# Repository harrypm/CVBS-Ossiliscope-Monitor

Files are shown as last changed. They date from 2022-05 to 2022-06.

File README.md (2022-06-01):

# CVBS-Oscilloscope-Monitor

This repository is a KiCAD transcription of a circuit by Alan Wolfe.

## Description

The following circuit converts a composite signal and splits the signal as such that it can display video on analog-style oscilloscopes using X,Y & Z inputs.

## Features

- LED indicator - Used for monitoring power
- Power jacks/pads - choice between barrel jack or 3.96mm headers
- BNC connectors for inputs and outputs

- 2 flexable versions depending on users needs

## [THT](CVBS-Ossiliscope-Monitor/Releases/THT) Through Hole (Hand Soldering Version)

This version is simmaller to the equipmnet its intended to be used with as every single part is hand user replaceable simply fabricate the bare boards and order the parts acording the to BOM list.

## [SMD](CVBS-Ossiliscope-Monitor/Releases/SMD) Surface Mount (Factory Frabrication Version)

This version following modern fabrication standards is intended for ease of automated fabraication allowing drag and drop 1-2-3 ordering from services like PCBway or JLCPCB.

## Additional information

Links :

* [PDF link](https://www.qsl.net/w2aew/W2AEW_NTSC_to_scope.pdf)
* [Youtube](https://www.youtube.com/watch?v=yf4kOMSPbM0&start=55)

## Credits

Transcription - Charles Garcia [@cgarcia2097](https://github.com/cgarcia2097)

Orignal Circuit - Alan Wolfe [PDF link](https://www.qsl.net/w2aew/W2AEW_NTSC_to_scope.pdf)

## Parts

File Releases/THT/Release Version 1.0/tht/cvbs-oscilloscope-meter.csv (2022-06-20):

Source: | /home/animeman/Documents/GitHub/CVBS-Ossiliscope-Monitor/tht/cvbs-oscilloscope-meter.kicad_sch
Date: | Mon 06 Jun 2022 10:54:27 PM EDT
Tool: | Eeschema 6.0.5
Generator: | /app/share/kicad/plugins/bom_csv_grouped_by_value.py
Component Count: | 54
Individual Components:
Item | Qty | Reference(s) | Value | LibPart | Footprint | Datasheet
 |  | C1 | 100n | Device:C | Capacitor_THT:C_Disc_D7.5mm_W2.5mm_P5.00mm | ~
 |  | C2 | 22n | Device:C | Capacitor_THT:C_Disc_D7.5mm_W2.5mm_P5.00mm | ~
 |  | C3 | 0.1u | Device:C | Capacitor_THT:C_Disc_D7.5mm_W2.5mm_P5.00mm | ~
 |  | C4 | 0.1u | Device:C | Capacitor_THT:C_Disc_D7.5mm_W2.5mm_P5.00mm | ~
 |  | C5 | 10n | Device:C | Capacitor_THT:C_Disc_D7.5mm_W2.5mm_P5.00mm | ~
 |  | C6 | 10u | Device:C_Polarized_Small_US | Capacitor_THT:CP_Radial_D8.0mm_P3.50mm | ~
 |  | C7 | 0.1u | Device:C_Small | Capacitor_THT:C_Disc_D7.5mm_W2.5mm_P5.00mm | ~
 |  | C8 | 10u | Device:C_Polarized_Small_US | Capacitor_THT:CP_Radial_D8.0mm_P3.50mm | ~
 |  | C9 | 0.33u | Device:C_Small | Capacitor_THT:C_Disc_D7.5mm_W2.5mm_P5.00mm | ~
 |  | C10 | 0.1u | Device:C_Small | Capacitor_THT:C_Disc_D7.5mm_W2.5mm_P5.00mm | ~
 |  | C11 | 10u | Device:C_Polarized_Small_US | Capacitor_THT:CP_Radial_D8.0mm_P3.50mm | ~
 |  | C16 | 10u | Device:C_Polarized_Small_US | Capacitor_THT:CP_Radial_D8.0mm_P3.50mm | ~
 |  | C17 | 0.1u | Device:C_Small | Capacitor_THT:C_Disc_D7.5mm_W2.5mm_P5.00mm | ~
 |  | D1 | 1N4148 | Device:D_Filled | Diode_THT:D_DO-35_SOD27_P7.62mm_Horizontal | ~
 |  | D2 | 1N4148 | Device:D_Filled | Diode_THT:D_DO-35_SOD27_P7.62mm_Horizontal | ~
 |  | D3 | Indicator | Device:LED_Filled | LED_THT:LED_D5.0mm | ~
 |  | J1 | Conn_Coaxial_Power | Connector:Conn_Coaxial_Power | Connector_Coaxial:BNC_TEConnectivity_1478035_Horizontal | ~
 |  | J2 | Conn_Coaxial_Power | Connector:Conn_Coaxial_Power | Connector_Coaxial:BNC_TEConnectivity_1478035_Horizontal | ~
 |  | J3 | Conn_Coaxial_Power | Connector:Conn_Coaxial_Power | Connector_Coaxial:BNC_TEConnectivity_1478035_Horizontal | ~
 |  | J4 | Conn_Coaxial_Power | Connector:Conn_Coaxial_Power | Connector_Coaxial:BNC_TEConnectivity_1478035_Horizontal | ~
 |  | J5 | Barrel_Jack_Switch | Connector:Barrel_Jack_Switch | Connector_BarrelJack:BarrelJack_GCT_DCJ200-10-A_Horizontal | ~
 |  | J6 | Molex 3.96mm | Connector_Generic:Conn_01x02 | Connector_Molex:Molex_KK-396_A-41791-0002_1x02_P3.96mm_Vertical | ~
 |  | L1 | 22u | Device:L | Inductor_THT:L_Axial_L11.0mm_D4.5mm_P15.24mm_Horizontal_Fastron_MECC | ~
 |  | MK1 | MountingHole_Pad | Mechanical:MountingHole_Pad | Mounting_Holes:MountingHole_3.2mm_M3_ISO7380 | ~
 |  | MK2 | MountingHole_Pad | Mechanical:MountingHole_Pad | Mounting_Holes:MountingHole_3.2mm_M3_ISO7380 | ~
 |  | MK3 | MountingHole_Pad | Mechanical:MountingHole_Pad | Mounting_Holes:MountingHole_3.2mm_M3_ISO7380 | ~
 |  | MK4 | MountingHole_Pad | Mechanical:MountingHole_Pad | Mounting_Holes:MountingHole_3.2mm_M3_ISO7380 | ~
 |  | Q1 | 2N3906 | Transistor_BJT:2N3906 | Package_TO_SOT_THT:TO-92_Inline | https://www.onsemi.com/pub/Collateral/2N3906-D.PDF
 |  | Q2 | 2N3906 | Transistor_BJT:2N3906 | Package_TO_SOT_THT:TO-92_Inline | https://www.onsemi.com/pub/Collateral/2N3906-D.PDF
 |  | Q3 | 2N3904 | Transistor_BJT:2N3904 | Package_TO_SOT_THT:TO-92_Inline | https://www.onsemi.com/pub/Collateral/2N3903-D.PDF
 |  | Q4 | 2N3904 | Transistor_BJT:2N3904 | Package_TO_SOT_THT:TO-92_Inline | https://www.onsemi.com/pub/Collateral/2N3903-D.PDF
 |  | Q5 | 2N3904 | Transistor_BJT:2N3904 | Package_TO_SOT_THT:TO-92_Inline | https://www.onsemi.com/pub/Collateral/2N3903-D.PDF
 |  | Q6 | 2N3904 | Transistor_BJT:2N3904 | Package_TO_SOT_THT:TO-92_Inline | https://www.onsemi.com/pub/Collateral/2N3903-D.PDF
 |  | R1 | 6.8k | Device:R_US | Resistor_THT:R_Axial_DIN0207_L6.3mm_D2.5mm_P10.16mm_Horizontal | ~
 |  | R2 | 6.8k | Device:R_US | Resistor_THT:R_Axial_DIN0207_L6.3mm_D2.5mm_P10.16mm_Horizontal | ~
 |  | R3 | 180 | Device:R_US | Resistor_THT:R_Axial_DIN0207_L6.3mm_D2.5mm_P10.16mm_Horizontal | ~
 |  | R4 | 5.6k | Device:R_US | Resistor_THT:R_Axial_DIN0207_L6.3mm_D2.5mm_P10.16mm_Horizontal | ~
 |  | R5 | 2.2k | Device:R_US | Resistor_THT:R_Axial_DIN0207_L6.3mm_D2.5mm_P10.16mm_Horizontal | ~
 |  | R6 | 3.3k | Device:R_US | Resistor_THT:R_Axial_DIN0207_L6.3mm_D2.5mm_P10.16mm_Horizontal | ~
 |  | R7 | 680k | Device:R_US | Resistor_THT:R_Axial_DIN0207_L6.3mm_D2.5mm_P10.16mm_Horizontal | ~
 |  | R8 | 68k | Device:R_US | Resistor_THT:R_Axial_DIN0207_L6.3mm_D2.5mm_P10.16mm_Horizontal | ~
 |  | R9 | 680 | Device:R_US | Resistor_THT:R_Axial_DIN0207_L6.3mm_D2.5mm_P10.16mm_Horizontal | ~
 |  | R10 | 3.3k | Device:R_US | Resistor_THT:R_Axial_DIN0207_L6.3mm_D2.5mm_P10.16mm_Horizontal | ~
 |  | R11 | 3.3k | Device:R_US | Resistor_THT:R_Axial_DIN0207_L6.3mm_D2.5mm_P10.16mm_Horizontal | ~
 |  | R12 | 2.2k | Device:R_US | Resistor_THT:R_Axial_DIN0207_L6.3mm_D2.5mm_P10.16mm_Horizontal | ~
 |  | R13 | 2.2k | Device:R_US | Resistor_THT:R_Axial_DIN0207_L6.3mm_D2.5mm_P10.16mm_Horizontal | ~
 |  | R14 | 4.7k | Device:R_US | Resistor_THT:R_Axial_DIN0207_L6.3mm_D2.5mm_P10.16mm_Horizontal | ~
 |  | R15 | 68k | Device:R_US | Resistor_THT:R_Axial_DIN0207_L6.3mm_D2.5mm_P10.16mm_Horizontal | ~
 |  | R16 | 2.4k | Device:R_US | Resistor_THT:R_Axial_DIN0207_L6.3mm_D2.5mm_P10.16mm_Horizontal | ~
 |  | RV1 | 1k | Device:R_Potentiometer_US | Potentiometer_THT:Potentiometer_Piher_PC-16_Single_Vertical | ~
 |  | RV2 | 10k | Device:R_Potentiometer_US | Potentiometer_THT:Potentiometer_Piher_PC-16_Single_Vertical | ~
 |  | U1 | LM1881 | Video:LM1881 | Package_DIP:DIP-8_W7.62mm_Socket_LongPads
 |  | U2 | AD8032 | Device:Opamp_Dual | Package_DIP:DIP-8_W7.62mm_Socket_LongPads | ~
 |  | U3 | LM7809_TO220 | Regulator_Linear:LM7809_TO220 | Package_TO_SOT_THT:TO-220-3_Vertical | https://www.onsemi.cn/PowerSolutions/document/MC7800-D.PDF
Collated Components:
Item | Qty | Reference(s) | Value | LibPart | Footprint | Datasheet
1 | 1 | C1 | 100n | Device:C | Capacitor_THT:C_Disc_D7.5mm_W2.5mm_P5.00mm | ~
2 | 1 | C2 | 22n | Device:C | Capacitor_THT:C_Disc_D7.5mm_W2.5mm_P5.00mm | ~
3 | 2 | C3, C4 | 0.1u | Device:C | Capacitor_THT:C_Disc_D7.5mm_W2.5mm_P5.00mm | ~
4 | 1 | C5 | 10n | Device:C | Capacitor_THT:C_Disc_D7.5mm_W2.5mm_P5.00mm | ~
5 | 4 | C6, C8, C11, C16 | 10u | Device:C_Polarized_Small_US | Capacitor_THT:CP_Radial_D8.0mm_P3.50mm | ~
6 | 3 | C7, C10, C17 | 0.1u | Device:C_Small | Capacitor_THT:C_Disc_D7.5mm_W2.5mm_P5.00mm | ~
7 | 1 | C9 | 0.33u | Device:C_Small | Capacitor_THT:C_Disc_D7.5mm_W2.5mm_P5.00mm | ~
8 | 2 | D1, D2 | 1N4148 | Device:D_Filled | Diode_THT:D_DO-35_SOD27_P7.62mm_Horizontal | ~
9 | 1 | D3 | Indicator | Device:LED_Filled | LED_THT:LED_D5.0mm | ~
10 | 4 | J1, J2, J3, J4 | Conn_Coaxial_Power | Connector:Conn_Coaxial_Power | Connector_Coaxial:BNC_TEConnectivity_1478035_Horizontal | ~
11 | 1 | J5 | Barrel_Jack_Switch | Connector:Barrel_Jack_Switch | Connector_BarrelJack:BarrelJack_GCT_DCJ200-10-A_Horizontal | ~
12 | 1 | J6 | Molex 3.96mm | Connector_Generic:Conn_01x02 | Connector_Molex:Molex_KK-396_A-41791-0002_1x02_P3.96mm_Vertical | ~
13 | 1 | L1 | 22u | Device:L | Inductor_THT:L_Axial_L11.0mm_D4.5mm_P15.24mm_Horizontal_Fastron_MECC | ~
14 | 4 | MK1, MK2, MK3, MK4 | MountingHole_Pad | Mechanical:MountingHole_Pad | Mounting_Holes:MountingHole_3.2mm_M3_ISO7380 | ~
15 | 2 | Q1, Q2 | 2N3906 | Transistor_BJT:2N3906 | Package_TO_SOT_THT:TO-92_Inline | https://www.onsemi.com/pub/Collateral/2N3906-D.PDF
16 | 4 | Q3, Q4, Q5, Q6 | 2N3904 | Transistor_BJT:2N3904 | Package_TO_SOT_THT:TO-92_Inline | https://www.onsemi.com/pub/Collateral/2N3903-D.PDF
17 | 2 | R1, R2 | 6.8k | Device:R_US | Resistor_THT:R_Axial_DIN0207_L6.3mm_D2.5mm_P10.16mm_Horizontal | ~
18 | 1 | R3 | 180 | Device:R_US | Resistor_THT:R_Axial_DIN0207_L6.3mm_D2.5mm_P10.16mm_Horizontal | ~
19 | 1 | R4 | 5.6k | Device:R_US | Resistor_THT:R_Axial_DIN0207_L6.3mm_D2.5mm_P10.16mm_Horizontal | ~
20 | 3 | R5, R12, R13 | 2.2k | Device:R_US | Resistor_THT:R_Axial_DIN0207_L6.3mm_D2.5mm_P10.16mm_Horizontal | ~
21 | 3 | R6, R10, R11 | 3.3k | Device:R_US | Resistor_THT:R_Axial_DIN0207_L6.3mm_D2.5mm_P10.16mm_Horizontal | ~
22 | 1 | R7 | 680k | Device:R_US | Resistor_THT:R_Axial_DIN0207_L6.3mm_D2.5mm_P10.16mm_Horizontal | ~
23 | 2 | R8, R15 | 68k | Device:R_US | Resistor_THT:R_Axial_DIN0207_L6.3mm_D2.5mm_P10.16mm_Horizontal | ~
24 | 1 | R9 | 680 | Device:R_US | Resistor_THT:R_Axial_DIN0207_L6.3mm_D2.5mm_P10.16mm_Horizontal | ~
25 | 1 | R14 | 4.7k | Device:R_US | Resistor_THT:R_Axial_DIN0207_L6.3mm_D2.5mm_P10.16mm_Horizontal | ~
26 | 1 | R16 | 2.4k | Device:R_US | Resistor_THT:R_Axial_DIN0207_L6.3mm_D2.5mm_P10.16mm_Horizontal | ~
27 | 1 | RV1 | 1k | Device:R_Potentiometer_US | Potentiometer_THT:Potentiometer_Piher_PC-16_Single_Vertical | ~
28 | 1 | RV2 | 10k | Device:R_Potentiometer_US | Potentiometer_THT:Potentiometer_Piher_PC-16_Single_Vertical | ~
29 | 1 | U1 | LM1881 | Video:LM1881 | Package_DIP:DIP-8_W7.62mm_Socket_LongPads
30 | 1 | U2 | AD8032 | Device:Opamp_Dual | Package_DIP:DIP-8_W7.62mm_Socket_LongPads | ~
31 | 1 | U3 | LM7809_TO220 | Regulator_Linear:LM7809_TO220 | Package_TO_SOT_THT:TO-220-3_Vertical | https://www.onsemi.cn/PowerSolutions/document/MC7800-D.PDF

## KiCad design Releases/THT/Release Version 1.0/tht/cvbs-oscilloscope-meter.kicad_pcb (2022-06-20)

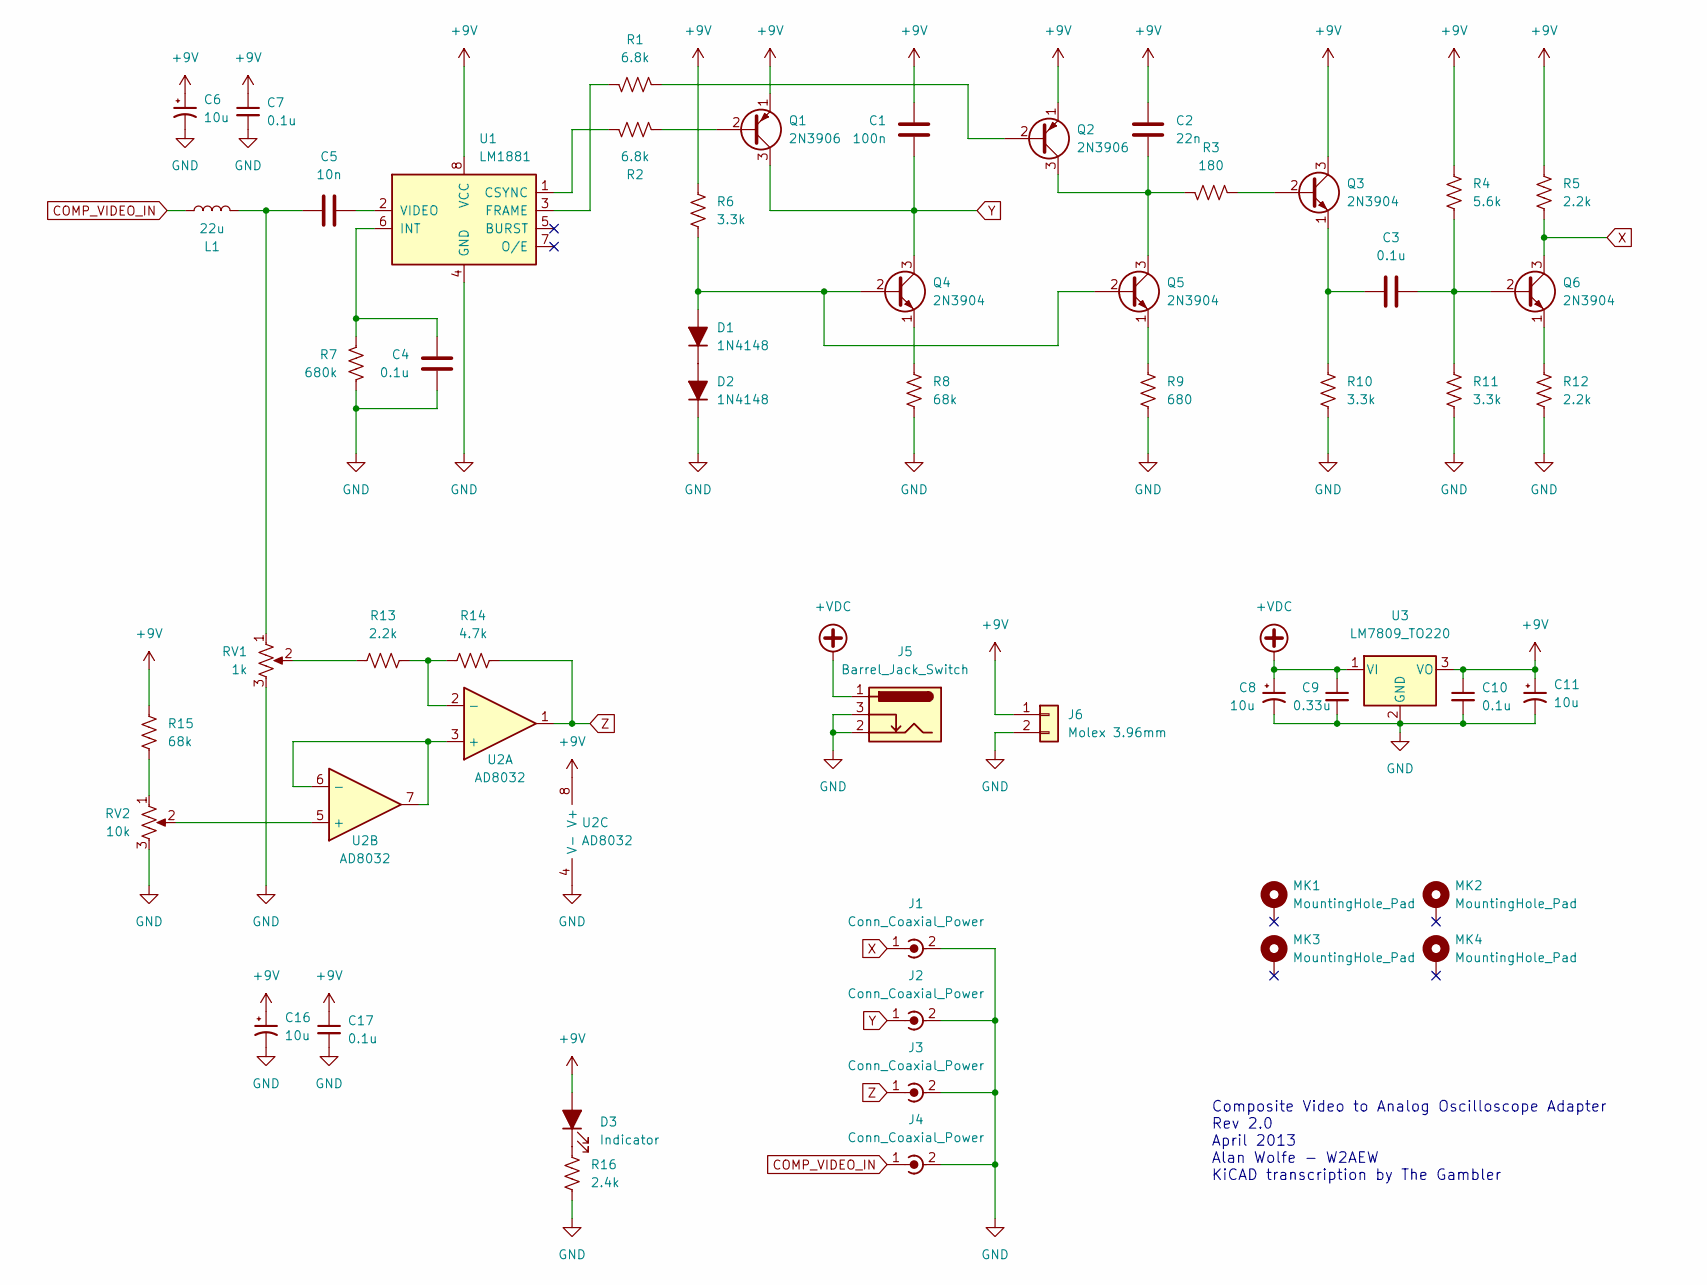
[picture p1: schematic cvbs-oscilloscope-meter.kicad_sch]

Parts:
C1: 100n; C_Disc_D7.5mm_W2.5mm_P5.00mm
C2: 22n; C_Disc_D7.5mm_W2.5mm_P5.00mm
C3, C4, C7, C10, C17: 0.1u; C_Disc_D7.5mm_W2.5mm_P5.00mm
C5: 10n; C_Disc_D7.5mm_W2.5mm_P5.00mm
C6, C8, C11, C16: 10u; CP_Radial_D8.0mm_P3.50mm
C9: 0.33u; C_Disc_D7.5mm_W2.5mm_P5.00mm
D1, D2: 1N4148; D_DO-35_SOD27_P7.62mm_Horizontal
D3: Indicator; LED_D5.0mm
J1, J2, J3, J4: Conn_Coaxial_Power; BNC_TEConnectivity_1478035_Horizontal
J5: Barrel_Jack_Switch; BarrelJack_GCT_DCJ200-10-A_Horizontal
J6: Molex 3.96mm; Molex_KK-396_A-41791-0002_1x02_P3.96mm_Vertical
L1: 22u; L_Axial_L11.0mm_D4.5mm_P15.24mm_Horizontal_Fastron_MECC
MK1, MK2, MK3, MK4: MountingHole_Pad; MountingHole_3.2mm_M3_ISO7380
Q1, Q2: 2N3906; TO-92_Inline
Q3, Q4, Q5, Q6: 2N3904; TO-92_Inline
R1, R2: 6.8k; R_Axial_DIN0207_L6.3mm_D2.5mm_P10.16mm_Horizontal
R3: 180; R_Axial_DIN0207_L6.3mm_D2.5mm_P10.16mm_Horizontal
R4: 5.6k; R_Axial_DIN0207_L6.3mm_D2.5mm_P10.16mm_Horizontal
R5, R12, R13: 2.2k; R_Axial_DIN0207_L6.3mm_D2.5mm_P10.16mm_Horizontal
R6, R10, R11: 3.3k; R_Axial_DIN0207_L6.3mm_D2.5mm_P10.16mm_Horizontal
R7: 680k; R_Axial_DIN0207_L6.3mm_D2.5mm_P10.16mm_Horizontal
R8, R15: 68k; R_Axial_DIN0207_L6.3mm_D2.5mm_P10.16mm_Horizontal
R9: 680; R_Axial_DIN0207_L6.3mm_D2.5mm_P10.16mm_Horizontal
R14: 4.7k; R_Axial_DIN0207_L6.3mm_D2.5mm_P10.16mm_Horizontal
R16: 2.4k; R_Axial_DIN0207_L6.3mm_D2.5mm_P10.16mm_Horizontal
RV1: 1k; Potentiometer_Piher_PC-16_Single_Vertical
RV2: 10k; Potentiometer_Piher_PC-16_Single_Vertical
U1: LM1881; DIP-8_W7.62mm_Socket_LongPads
U2: AD8032; DIP-8_W7.62mm_Socket_LongPads
U3: LM7809_TO220; TO-220-3_Vertical

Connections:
+9V: C1.2, C2.2, C6.1, C7.1, C10.1, C11.1, C16.1, C17.1, D3.2 (A), J6.1, Q1.1 (E), Q2.1 (E), Q3.3 (C), R4.1, R5.1, R6.1, R15.1, U1.8 (VCC), U2.8 (V+), U3.3 (VO)
+VDC: C8.1, C9.1, J5.1, U3.1 (VI)
COMP_VIDEO_IN: J4.1 (In), L1.1
GND: C4.1, C6.2, C7.2, C8.2, C9.2, C10.2, C11.2, C16.2, C17.2, D2.1 (K), J1.2 (Ext), J2.2 (Ext), J3.2 (Ext), J4.2 (Ext), J5.2, J5.3, J6.2, R7.1, R8.2, R9.2, R10.2, R11.2, R12.2, R16.2, RV1.3, RV2.3, U1.4 (GND), U2.4 (V-), U3.2 (GND)
unnamed: C2.1, Q2.3 (C), Q5.3 (C), R3.2
unnamed: C3.1, Q3.1 (E), R10.1
unnamed: C3.2, Q6.2 (B), R4.2, R11.1
unnamed: C4.2, R7.2, U1.6 (INT)
unnamed: C5.1, U1.2 (VIDEO)
unnamed: C5.2, L1.2, RV1.1
unnamed: D1.1 (K), D2.2 (A)
unnamed: D1.2 (A), Q4.2 (B), Q5.2 (B), R6.2
unnamed: D3.1 (K), R16.1
unnamed: Q1.2 (B), R2.2
unnamed: Q2.2 (B), R1.1
unnamed: Q3.2 (B), R3.1
unnamed: Q4.1 (E), R8.1
unnamed: Q5.1 (E), R9.1
unnamed: Q6.1 (E), R12.1
unnamed: R1.2, U1.3 (FRAME)
unnamed: R2.1, U1.1 (CSYNC)
unnamed: R13.1, RV1.2
unnamed: R13.2, R14.1, U2.2 (-)
unnamed: R15.2, RV2.1
unnamed: RV2.2, U2.5 (+)
unnamed: U2.3 (+), U2.6 (-), U2.7
X: J1.1 (In), Q6.3 (C), R5.2
Y: C1.1, J2.1 (In), Q1.3 (C), Q4.3 (C)
Z: J3.1 (In), R14.2, U2.1

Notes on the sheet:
Composite Video to Analog Oscilloscope Adapter Rev 2.0 April 2013 Alan Wolfe - W2AEW KiCAD transcription by The Gambler

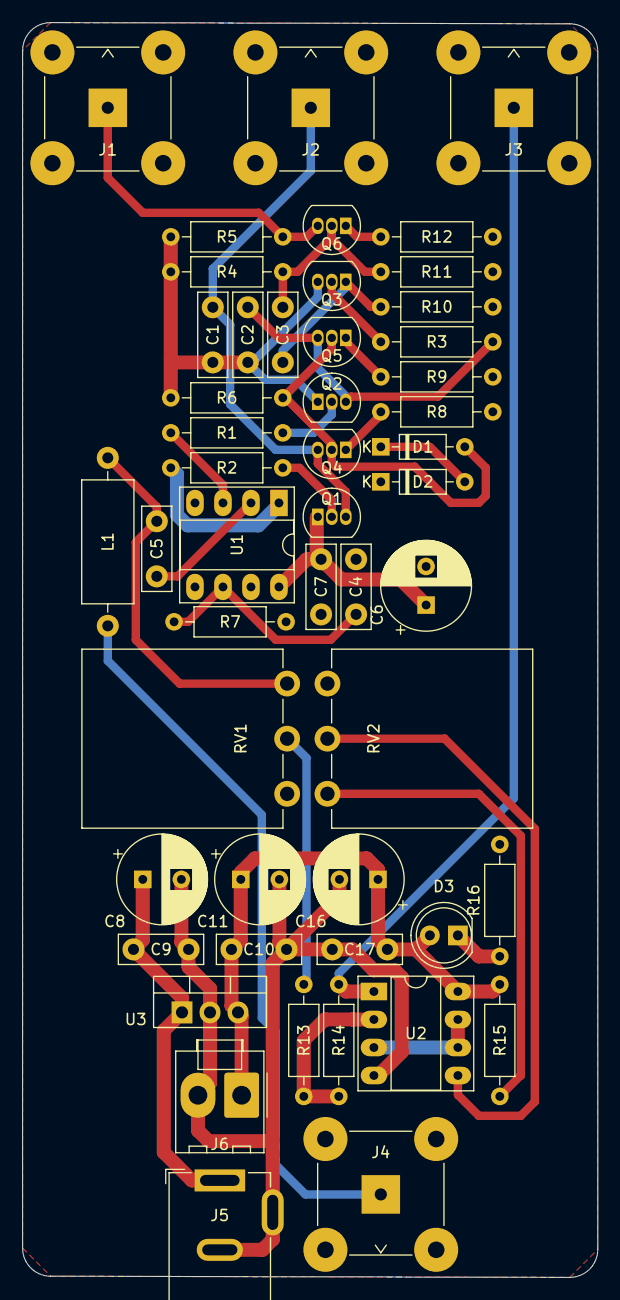
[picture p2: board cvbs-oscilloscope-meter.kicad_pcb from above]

Board: 2 copper layers, 52.2 x 113.8 mm, 50 parts (0 on the bottom side), 29 nets.

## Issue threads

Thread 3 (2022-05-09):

Power & Signal Input/Output Detection

harrypm, 2022-05-09:

cgarcia2097, 2022-05-09:
Please be more specific about what extras are to be added - Schematics and references are also appreciated

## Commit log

2022-05-06 Created initial schematic
    [cvbs-oscilloscope-meter.kicad_pcb, cvbs-oscilloscope-meter.kicad_sch]
2022-05-07 Created schematic
2022-05-08 Created PCB
    [cvbs-oscilloscope-meter.kicad_pcb]
2022-05-08 Finished initial routing
    Finished Routing - will need to check and revise
    [cvbs-oscilloscope-meter.kicad_pcb]
2022-05-08 New update
    - Updated README
    - Added power and LED circuitry
    [cvbs-oscilloscope-meter.kicad_pcb, cvbs-oscilloscope-meter.kicad_sch]
2022-05-16 Created SMD boards
    [cvbs-oscilloscope-meter.kicad_pcb, cvbs-oscilloscope-meter.kicad_sch]
2022-05-16 Updated THT
    Starting new routing for new schematic layout
    [cvbs-oscilloscope-meter.kicad_pcb]
2022-05-24 Started PCB layout v2
    [cvbs-oscilloscope-meter.kicad_pcb, cvbs-oscilloscope-meter.kicad_sch]
2022-05-24 Simple index
    [cvbs-oscilloscope-meter.kicad_pcb, cvbs-oscilloscope-meter.kicad_sch]
2022-06-20 Though Hole Release Version 1.0
    [cvbs-oscilloscope-meter-rounded.kicad_pcb, cvbs-oscilloscope-meter.csv, cvbs-oscilloscope-meter.kicad_pcb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]
